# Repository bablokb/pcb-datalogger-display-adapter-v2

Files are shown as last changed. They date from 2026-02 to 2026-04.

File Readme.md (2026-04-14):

KiCAD-Designfiles
=================

Here are the KiCAD (v7) design-files for a generic display-adapter-PCB.

The adapter supports the following displays:

  - Pimoroni Inky-Pack (and other display-packs with the same pinout)
  - Adafruit SPI-displays
  - WeAct-Studio 2.9" B/W e-Ink (with 2x4 connector)
  - Various generic SPI-TFT displays (many share the same pinout)

The pinout of the "input pins" is optimized for these datalogger PCB:

  - [Datalogger-v2 PCB](https://github.com/bablokb/pcb-datalogger-v2)
  - [Datalogger-v3 PCB](https://github.com/bablokb/pcb-datalogger-v3)

There is a minimal case available for the display, mainly to stabilze it:

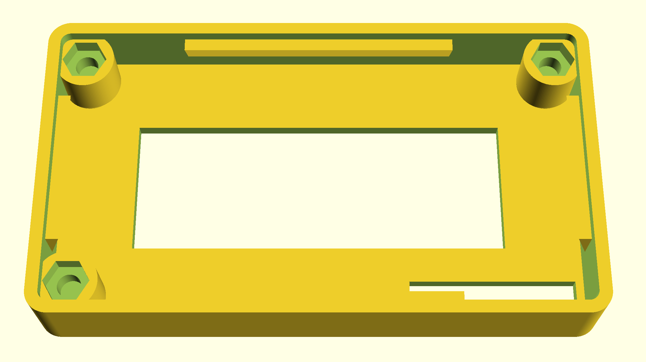
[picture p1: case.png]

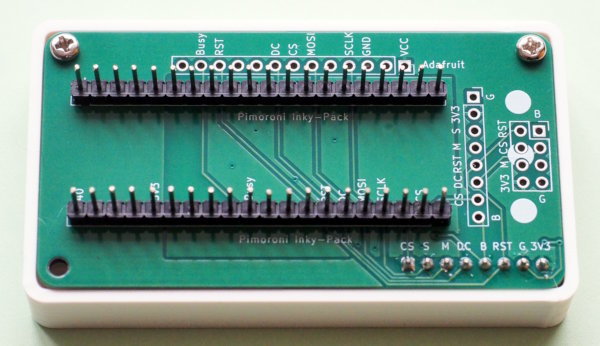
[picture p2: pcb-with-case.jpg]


Schematic
---------

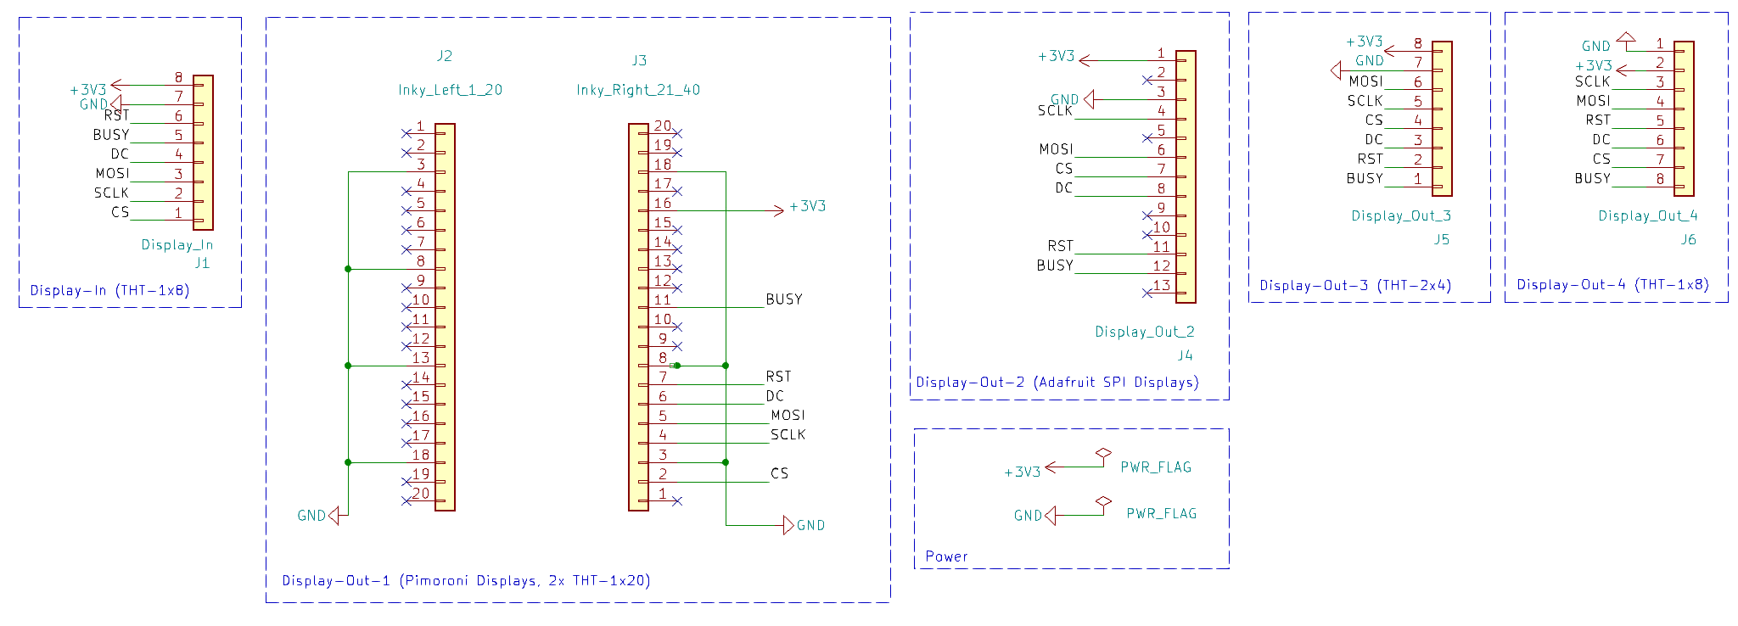
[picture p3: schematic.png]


Layout
------

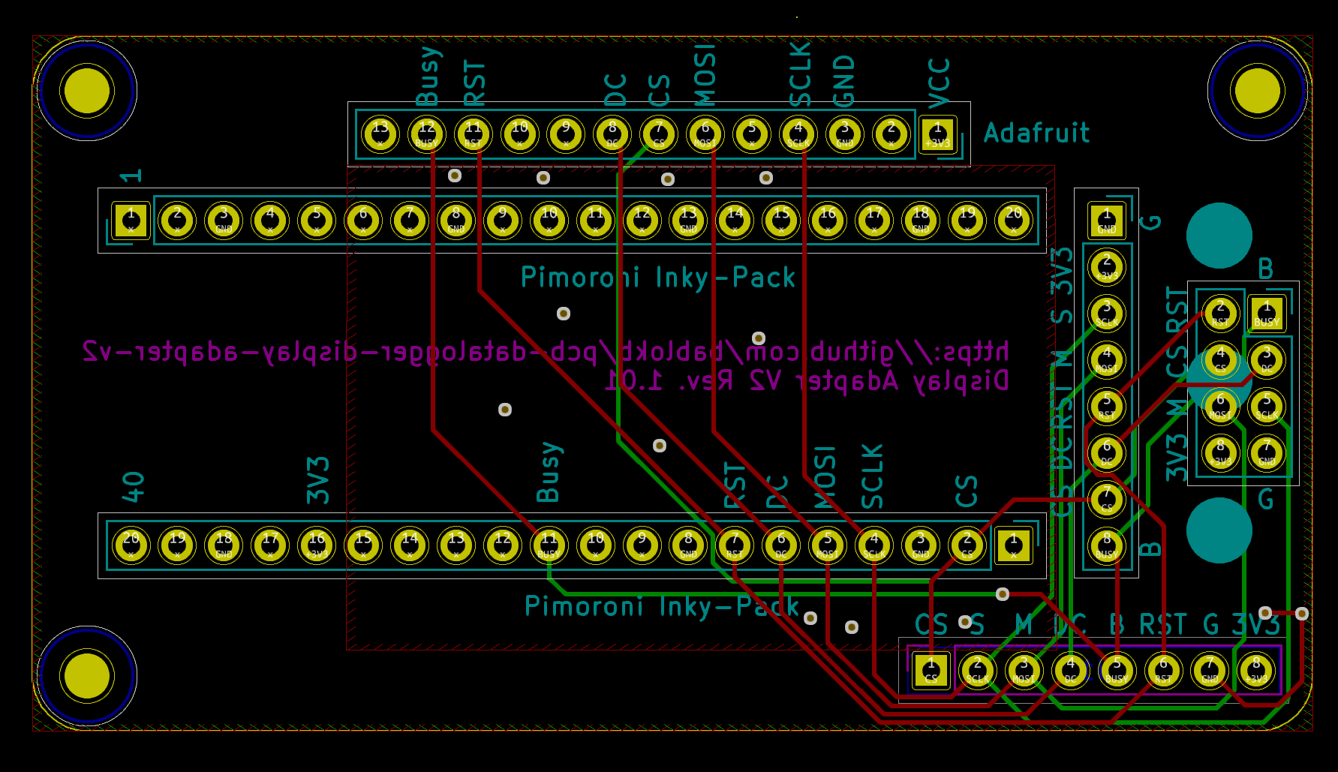
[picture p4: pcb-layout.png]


3D-Views
--------

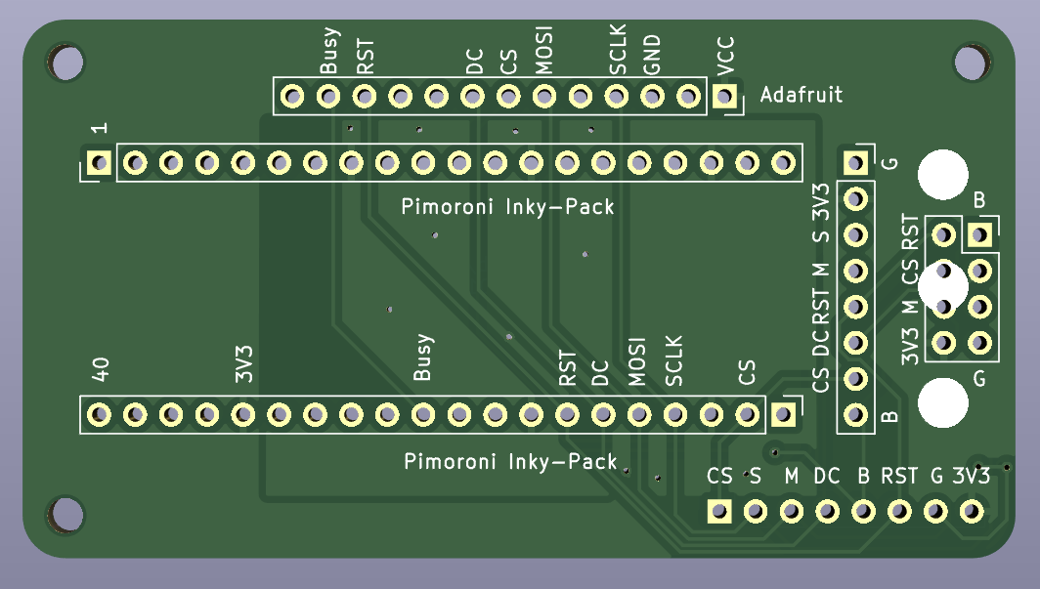
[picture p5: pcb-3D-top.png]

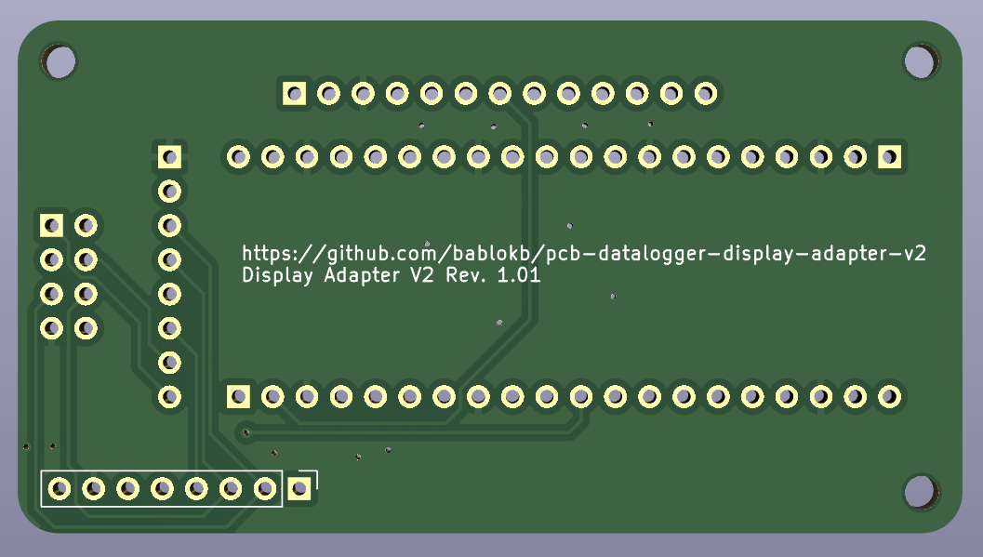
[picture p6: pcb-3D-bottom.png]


License
-------

[![CC BY-SA 4.0][cc-by-sa-shield]][cc-by-sa]

This work is licensed under a
[Creative Commons Attribution-ShareAlike 4.0 International
License][cc-by-sa].

[][cc-by-sa]

[cc-by-sa]: http://creativecommons.org/licenses/by-sa/4.0/
[cc-by-sa-image]: https://licensebuttons.net/l/by-sa/4.0/88x31.png
[cc-by-sa-shield]:
https://img.shields.io/badge/License-CC%20BY--SA%204.0-lightgrey.svg

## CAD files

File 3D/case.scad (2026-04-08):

// ---------------------------------------------------------------------------
// 3D-Model (OpenSCAD): Case for display.
//
// Author: Bernhard Bablok
// License: GPL3
//
// https://github.com/bablokb/pcb-datalogger-display-adapter-v2
// ---------------------------------------------------------------------------

include <BOSL2/std.scad>
include <modules/dimensions.scad>
include <modules/threaded_case.scad>

// dimensions
X_PCB  = 70;
Y_PCB  = 38;
Z_CASE = 10.4;
R_CASE = 10;        // inner rim

// cutout connector
X_CONN = 22;
Y_CONN =  4;
XO_CONN = 23.03;
YO_CONN = -15.7;

module case() {
  difference() {
    case_threaded(X_PCB, Y_PCB, z_case=Z_CASE, ruthex=false, screws=[1,1,0,1]);
    // cutout rim
    zmove(-FUZZ)
      cuboid([X_PCB-2*R_CASE,Y_PCB-2*R_CASE,BT+2*FUZZ], anchor=BOTTOM+CENTER);
    // cutout connector
    move([XO_CONN,YO_CONN,-FUZZ])
      cuboid([X_CONN,Y_CONN,BT+2*FUZZ], anchor=BOTTOM+CENTER);
  }
}

case();

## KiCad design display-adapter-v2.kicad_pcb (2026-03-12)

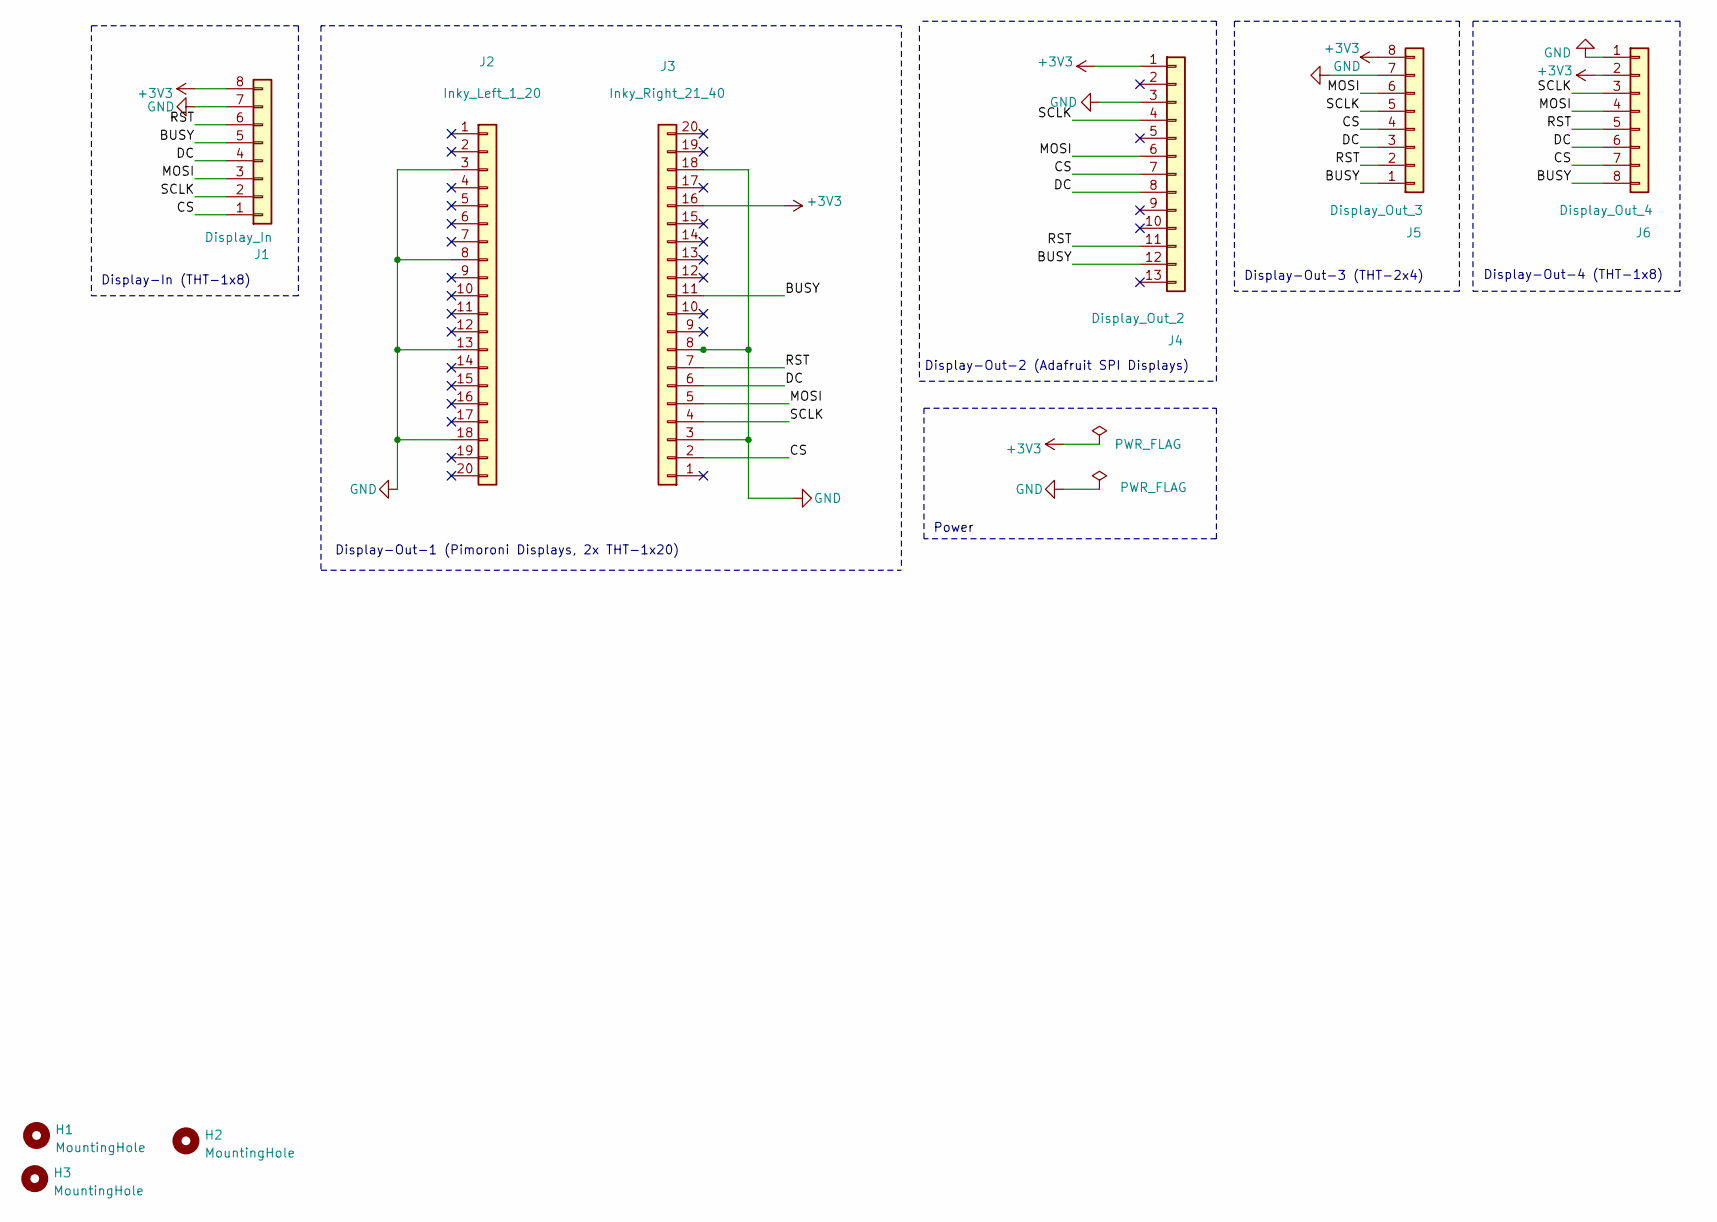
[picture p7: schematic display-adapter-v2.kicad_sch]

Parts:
H1, H2, H3: MountingHole; MountingHole_2.5mm
J1: Display_In; PinHeader_1x08_P2.54mm_Vertical; LCSC C5143489
J2: Inky_Left_1_20; PinHeader_1x20_P2.54mm_Vertical; LCSC C725952
J3: Inky_Right_21_40; PinHeader_1x20_P2.54mm_Vertical; LCSC C725952
J4: Display_Out_2; PinSocket_1x13_P2.54mm_Vertical
J5: Display_Out_3; PinSocket_2x04_P2.54mm_Vertical
J6: Display_Out_4; PinSocket_1x08_P2.54mm_Vertical; LCSC C5143489

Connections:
+3V3: J1.8, J3.16, J4.1, J5.8, J6.2
/BUSY: J1.5, J3.11, J4.12, J5.1, J6.8
/CS: J1.1, J3.2, J4.7, J5.4, J6.7
/DC: J1.4, J3.6, J4.8, J5.3, J6.6
/MOSI: J1.3, J3.5, J4.6, J5.6, J6.4
/RST: J1.6, J3.7, J4.11, J5.2, J6.5
/SCLK: J1.2, J3.4, J4.4, J5.5, J6.3
GND: J1.7, J2.3, J2.8, J2.13, J2.18, J3.3, J3.8, J3.18, J4.3, J5.7, J6.1

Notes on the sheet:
Display-Out-1 (Pimoroni Displays, 2x THT-1x20)
Display-Out-3 (THT-2x4)
Display-Out-2 (Adafruit SPI Displays)
Display-Out-4 (THT-1x8)
Power
Display-In (THT-1x8)

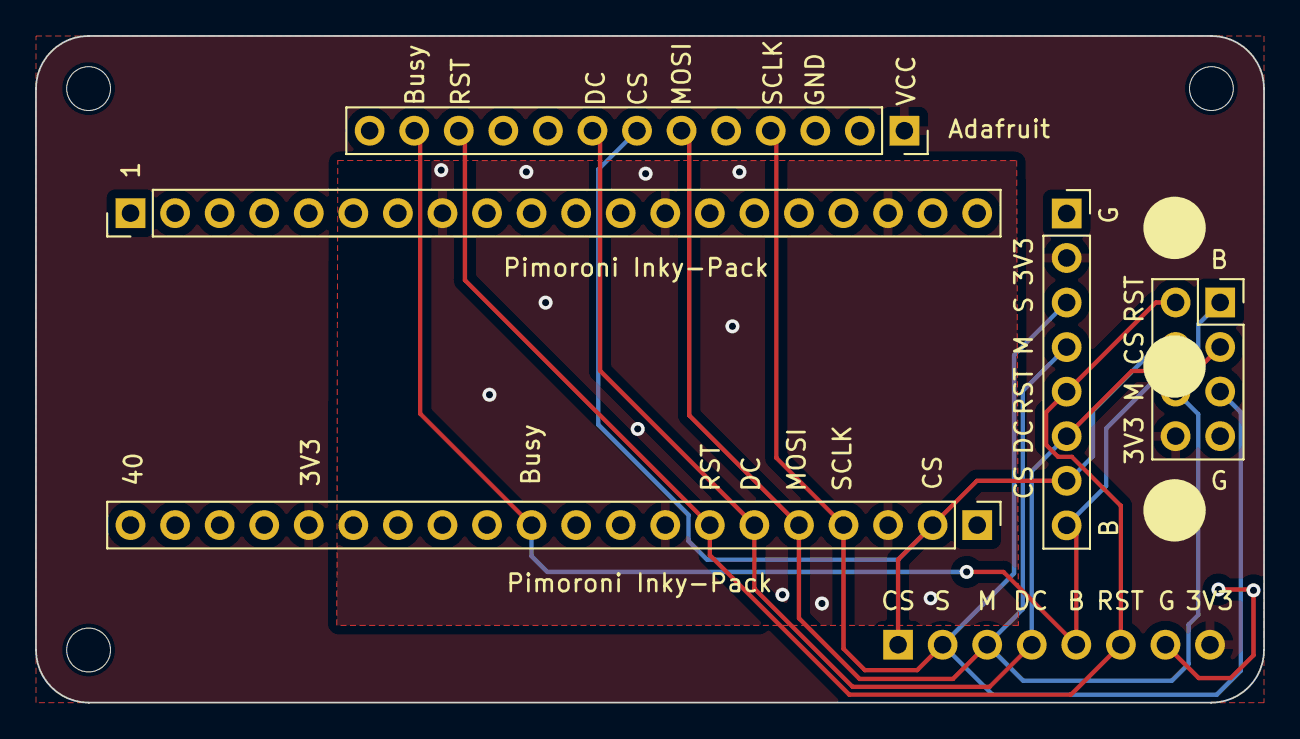
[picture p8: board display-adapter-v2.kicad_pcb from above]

Board: 2 copper layers, 70.0 x 38.0 mm, 9 parts (1 on the bottom side), 8 nets.

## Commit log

2026-02-23 initial commit (Rev. 1.00)
    [display-adapter-v2.kicad_pcb, display-adapter-v2.kicad_sch]
2026-03-12 bugfix: wrong 1x21 instead of 1x20 footprint for Inky-connectors
    [display-adapter-v2.kicad_pcb, display-adapter-v2.kicad_sch]
2026-04-08 ignore 3D print files
2026-04-08 initial version of case for display-adapter
    [case.scad]
2026-04-14 added images of case
